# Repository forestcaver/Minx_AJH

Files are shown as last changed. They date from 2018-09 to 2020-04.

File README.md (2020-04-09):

# Minx_AJH

minx

Buffered multiple based on Mutable Instruments Links

v1.1 normals the first input jack to ground (if you have v1.0 boards - it's trivial to just jumper the jack !)

BOM spreadsheet is untested - I havent built from this BOM ! Pls check carefully if you use it.

Please note - pcbs and panels are being sold by other people - I have no connection, financial or otherwise, to anyone selling pcbs and panels, hence I feel no commercial obligation to offer build support! I am just freely offering up these designs! Enjoy!

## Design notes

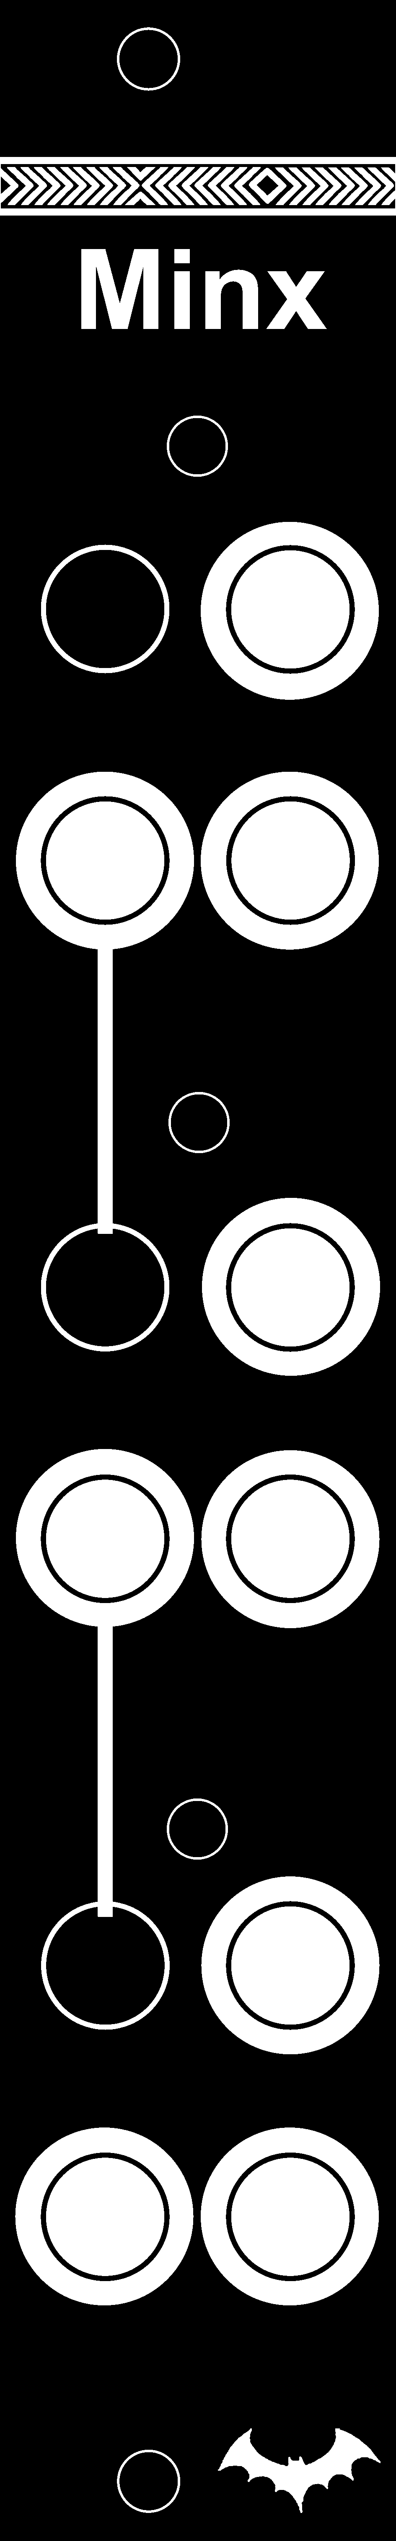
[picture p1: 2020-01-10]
minx_panel_01.bmp

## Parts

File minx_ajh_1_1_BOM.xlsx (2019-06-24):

minx_ajh_1_1_BOM
Qty | Value | Device | Package | Parts | Description | Ref. Mouser
3 | 1.0k | R-US_R0603 | R0603 | R3, R7, R14 | RESISTOR, American symbol | 667-ERJ3-EKF1001V
6 | 100n | C-USC0603 | C0603 | C3, C4, C5, C6, C7, C8 | CAPACITOR, American symbol | 81-GRM188R71E104JA1J
3 | 10M | R-US_R0603 | R0603 | R1, R8, R15 | RESISTOR, American symbol | 603-RC0603FR-0710ML
2 | 1N5819HW | DIODE-SOD123 | SOD123 | D1, D2 | DIODE | 621-1N5819HW-F
2 | 4.7u | CPOL-USA | PANASONIC_A | C1, C2 | POLARIZED CAPACITOR, American symbol | 647-UWX1E4R7MCL2
9 | 51 | R-US_R0603 | R0603 | R2, R4, R5, R6, R9, R10, R11, R12, R13 | RESISTOR, American symbol | 667-ERJ-3EKF51R0V
1 | M05X2PTH | M05X2PTH | AVR_ICSP | JP1 | Header 5x2 | 649-67996-410HLF
3 | OPA4171 | TL074PW | TSSOP14 | IC1, IC2, IC3 | OP AMP | 595-OPA4171AIPW
12 | PJ301_THONKICONN6 | PJ301_THONKICONN6 | WQP_PJ_301M6 | J1, J2, J3, J4, J5, J6, J7, J8, J9, J10, J11, J12
3 | WP937EGW | LED3MM | LED3MM | LED1, LED2, LED3 | LED | 604-WP937EGW

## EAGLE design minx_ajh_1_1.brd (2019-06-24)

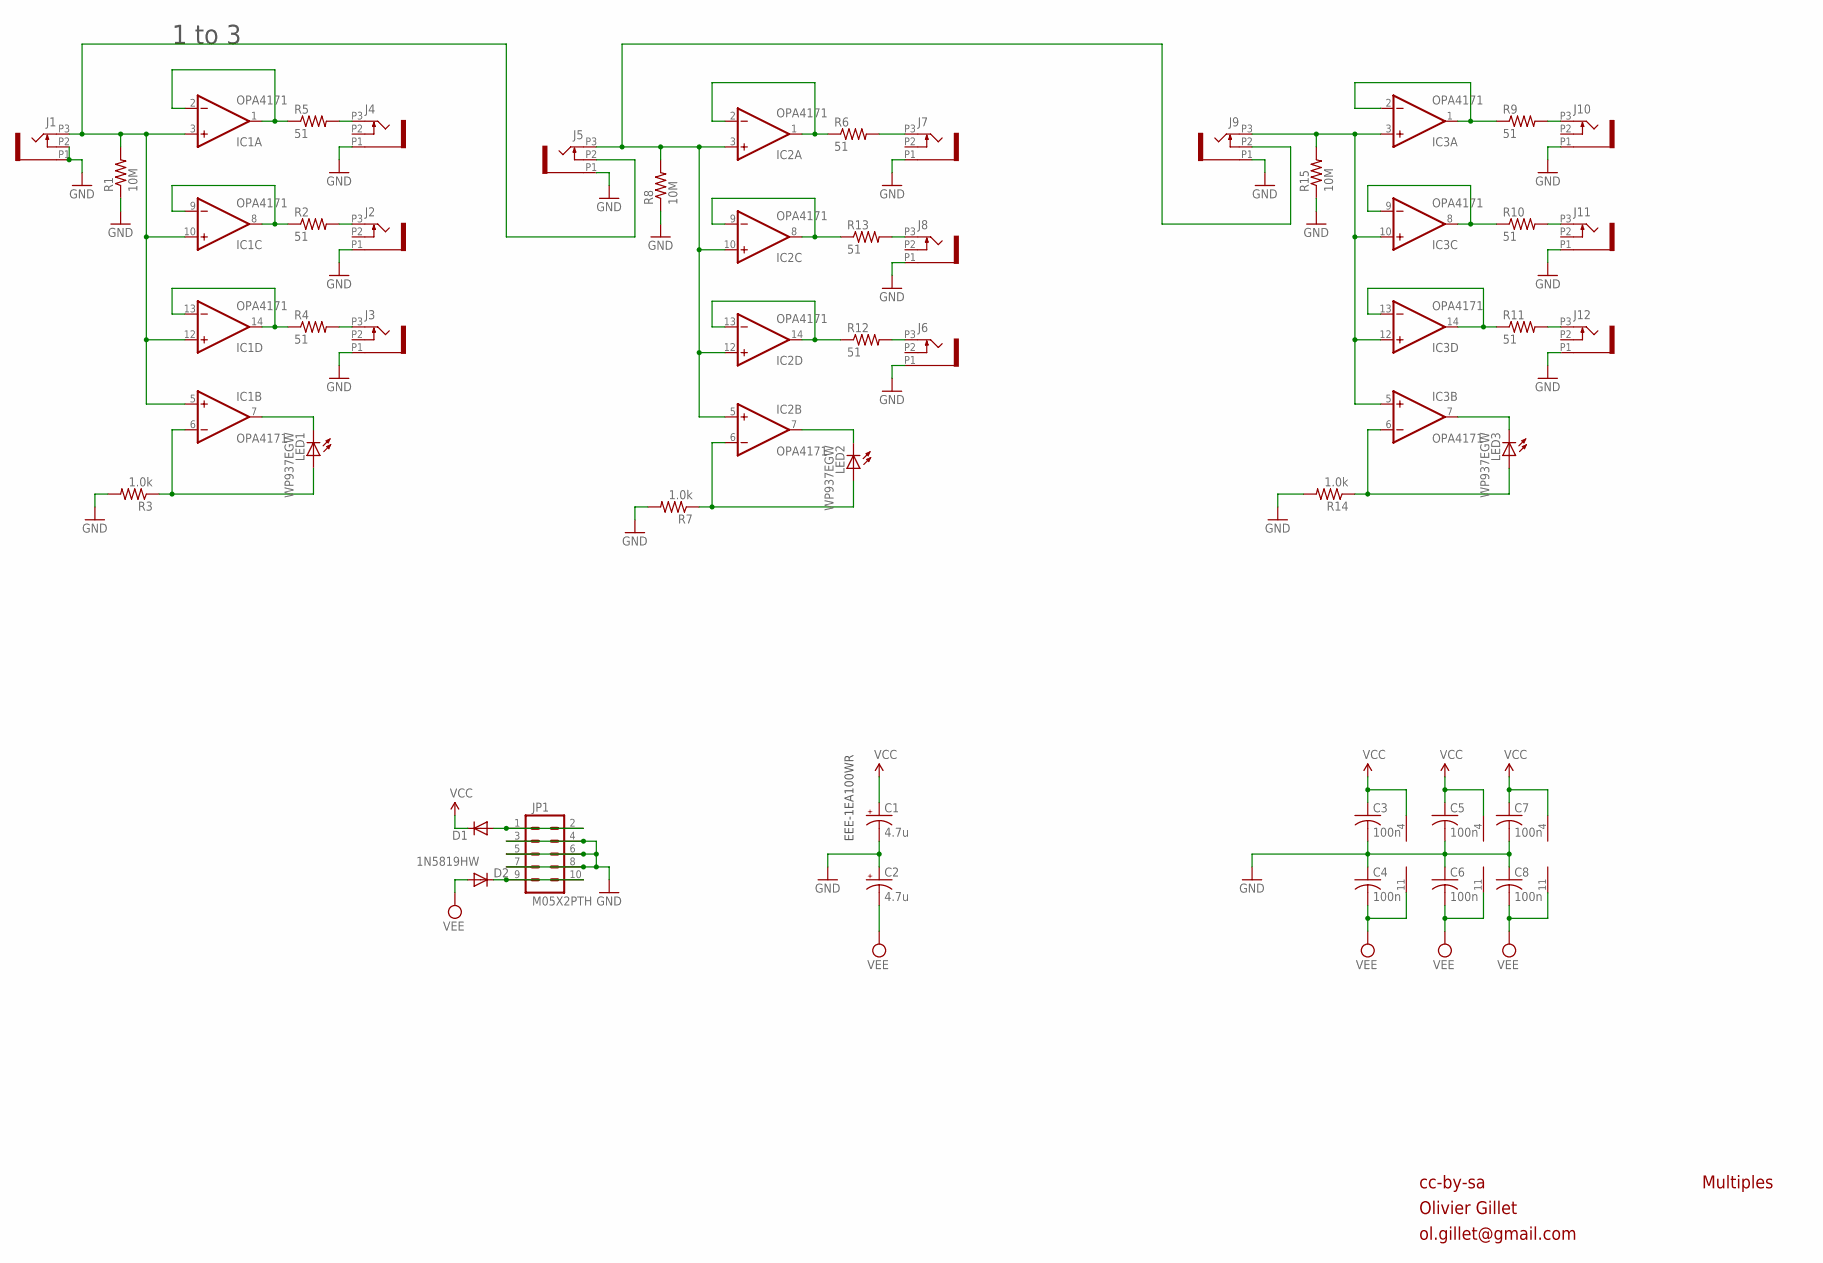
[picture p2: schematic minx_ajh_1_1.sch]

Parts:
C1, C2: 4.7u; PANASONIC_A
C3, C4, C5, C6, C7, C8: 100n; C0603
D1, D2: 1N5819HW; SOD123
IC1, IC2, IC3: OPA4171; TSSOP14
J1, J2, J3, J4, J5, J6, J7, J8, J9, J10, J11, J12: PJ301_THONKICONN6; WQP_PJ_301M6
JP1: M05X2PTH; AVR_ICSP
LED1, LED2, LED3: WP937EGW; LED3MM
R1, R8, R15: 10M; R0603
R2, R4, R5, R6, R9, R10, R11, R12, R13: 51; R0603
R3, R7, R14: 1.0k; R0603

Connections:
GND: C1.-, C2.+, C3.2, C4.1, C5.2, C6.1, C7.2, C8.1, J1.P1 (1), J1.P2 (2), J2.P1 (1), J3.P1 (1), J4.P1 (1), J5.P1 (1), J6.P1 (1), J7.P1 (1), J8.P1 (1), J9.P1 (1), J10.P1 (1), J11.P1 (1), J12.P1 (1), JP1.3, JP1.4, JP1.5, JP1.6, JP1.7, JP1.8, R1.1, R3.2, R7.2, R8.1, R14.2, R15.1
unnamed: IC2.8 (OUT), IC2.9 (-IN), R13.1
unnamed: IC3.1 (OUT), IC3.2 (-IN), R9.1
unnamed: J2.P3 (3), R2.2
unnamed: J3.P3 (3), R4.2
unnamed: IC1.13 (-IN), IC1.14 (OUT), R4.1
unnamed: D1.A, JP1.1, JP1.2
unnamed: IC3.13 (-IN), IC3.14 (OUT), R11.1
unnamed: IC1.7 (OUT), LED1.K (C)
unnamed: J7.P3 (3), R6.2
unnamed: IC2.1 (OUT), IC2.2 (-IN), R6.1
unnamed: J4.P3 (3), R5.2
unnamed: J8.P3 (3), R13.2
unnamed: J6.P3 (3), R12.2
unnamed: IC3.7 (OUT), LED3.K (C)
unnamed: J12.P3 (3), R11.2
unnamed: J11.P3 (3), R10.2
unnamed: IC3.6 (-IN), LED3.A, R14.1
unnamed: IC3.8 (OUT), IC3.9 (-IN), R10.1
unnamed: D2.C, JP1.9, JP1.10
unnamed: IC1.6 (-IN), LED1.A, R3.1
unnamed: IC3.3 (+IN), IC3.5 (+IN), IC3.10 (+IN), IC3.12 (+IN), J9.P3 (3), R15.2
unnamed: J10.P3 (3), R9.2
unnamed: IC1.3 (+IN), IC1.5 (+IN), IC1.10 (+IN), IC1.12 (+IN), J1.P3 (3), J5.P2 (2), R1.2
unnamed: IC2.13 (-IN), IC2.14 (OUT), R12.1
unnamed: IC1.1 (OUT), IC1.2 (-IN), R5.1
unnamed: IC2.7 (OUT), LED2.K (C)
unnamed: IC1.8 (OUT), IC1.9 (-IN), R2.1
unnamed: IC2.3 (+IN), IC2.5 (+IN), IC2.10 (+IN), IC2.12 (+IN), J5.P3 (3), J9.P2 (2), R8.2
unnamed: IC2.6 (-IN), LED2.A, R7.1
VCC: C1.+, C3.1, C5.1, C7.1, D1.C, IC1.4 (V+), IC2.4 (V+), IC3.4 (V+)
VEE: C2.-, C4.2, C6.2, C8.2, D2.A, IC1.11 (V-), IC2.11 (V-), IC3.11 (V-)

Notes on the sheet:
cc-by-sa
Olivier Gillet
ol.gillet@gmail.com
Multiples
1 to 3
EEE-1EA100WR

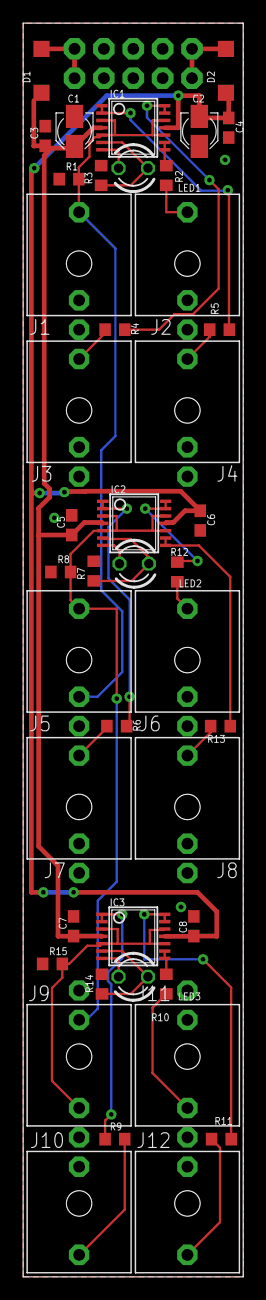
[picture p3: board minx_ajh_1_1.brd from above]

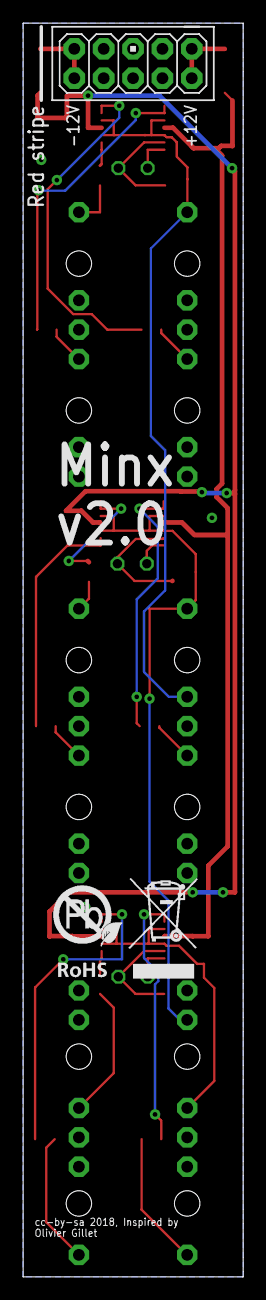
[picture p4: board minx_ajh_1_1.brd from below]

Board: 2 copper layers, 19.0 x 108.4 mm, 45 parts (2 on the bottom side), 32 nets.

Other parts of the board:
U$2: ROHS

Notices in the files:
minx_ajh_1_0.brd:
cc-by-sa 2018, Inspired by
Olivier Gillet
